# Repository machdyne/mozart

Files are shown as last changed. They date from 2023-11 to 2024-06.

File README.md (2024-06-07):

# Mozart Motherboard

Mozart is a motherboard that when paired with a [Sechzig](https://github.com/machdyne/sechzig) compute module can function as a computer.

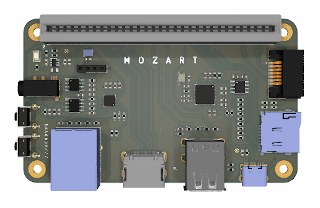
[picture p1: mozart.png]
Mozart Motherboard


This repo contains schematics, PCB layouts, pinouts and documentation.

Find more information on the [Mozart product page](https://machdyne.com/product/mozart-motherboard/).

## Using Mozart

Mozart requires a Sechzig module to power on. **When inserting a Sechzig module, make sure that pin 2 on Mozart and pin 2 on the module are both on the same side.**

## Firmware

Mozart has a JTAG and USB CDC interface that are both accessible on the USB-C port. These interfaces are provided by a [fork of pico-dirtyJtag](https://github.com/machdyne/mozart/tree/main/firmware). You can update the RP2040 firmware by holding down the BOOT button and then applying power.

To build the firmware from source:

```
$ cd firmware/pico-dirtyJtag
$ mkdir build
# if your Mozart has Zetta flash:
$ cmake ..
# or if your Mozart has Adesto flash:
$ cmake .. -DPICO_DEFAULT_BOOT_STAGE2_FILE=/your-pico-sdk-directory/pico-sdk/src/rp2_common/boot_stage2/boot2_generic_03h.S
# then
$ make
```

## Programming

Program the configuration SRAM of a Sechzig module:

```
sudo openFPGALoader -c dirtyJtag image.bit
```

Program the configuration flash on a Sechzig ML module:

```
sudo openFPGALoader -f -c dirtyJtag image.bit
```

Program the configuration flash on a Sechzig MX1 module:

```
sudo openFPGALoader -c dirtyJtag -f image.bit --fpga-part xc7a35tftg256
```

## Linux

See the [Kakao Linux](https://github.com/machdyne/kakao) repo for the latest instructions.

## Pinouts

### LVDS Port

Mozart has an experimental SATA-style LVDS port. SATA is not supported.

| Pin | Signal |
| --- | --- |
| 1 | GND |
| 2 | DS2\_P |
| 3 | DS2\_N |
| 4 | GND |
| 5 | DS1\_P |
| 6 | DS1\_N |
| 7 | GND |

### Audio Jack

Mozart has line-level audio output via a 3.5mm jack.

| Pin | Signal |
| --- | --- |
| S | GND |
| R2 | NC |
| R1 | AUDIO\_R |
| T | AUDIO\_L |

### Audio Amp Port

Mozart has a socket for an optional audio amplifier, so that speakers
can be connected to the DAC output.

| Pin | Signal |
| --- | --- |
| 1 | 5V0 |
| 2 | AUDIO\_L |
| 3 | AUDIO\_R |
| 4 | GND |

### DDMI Port

See the [DDMI repo](https://github.com/machdyne/ddmi) for details.

## Funding

This project was partially funded through the NGI0 Entrust Fund, a fund established by NLnet with financial support from the European Commission's Next Generation Internet programme.

## License

This project is released under the [CERN-OHL-P](LICENSE.txt) license.

Note: You can use these designs for commercial purposes but we ask that instead of producing exact clones, that you either replace our trademarks and logos with your own or add your own next to ours.

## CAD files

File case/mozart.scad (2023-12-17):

/*
 * Mozart Case
 * Copyright (c) 2023 Lone Dynamics Corporation. All rights reserved.
 *
 * required hardware:
 *  - 2 x M3 x 12mm bolts
 *  - 2 x M3 x 25mm countersunk bolts
 *  - 4 x M3 nuts
 * 
 */

$fn = 100;

board_width = 60;
board_thickness = 1.404;
board_length = 100;
board_height = 1.6;
board_spacing = 2;

wall = 1.5;

//translate([1,2,-1.6]) ld9_board();

translate([0,0,0])
	ld9_case_top();

translate([0,0,-6.5])
	ld9_case_bottom();

module ld9_board() {
	
	difference() {
		union() {
			color([0,0.5,0])
				roundedcube(board_width,board_length,board_thickness, 5);
			color([0.2,0.2,0.2])
				translate([0.75,8,0]) cube([9.2, 82.7, 55]);
				//translate([0.25,8,0]) cube([9.2, 82.7, 15]);
			color([0.2,0.2,0.2])
				translate([35.725-(7.5/2),-5,0])
					cube([7.5,10,7.5]);

		}
		translate([5, 5, -1]) cylinder(d=3.2, h=100);
		translate([5, 95, -1]) cylinder(d=3.2, h=100);
		translate([55, 5, -1]) cylinder(d=3.2, h=100);
		translate([55, 95, -1]) cylinder(d=3.2, h=100);
	}	
		
}

module ld9_case_top() {

		translate([0,25,19])
				rotate([90,0,270])
					translate([-45,-11,5])
						linear_extrude(1)
							text("M O Z A R T", size=4, halign="center",
								font="Liberation Sans:style=Bold");


		// addl supports
		translate([35.725-(7.5/2)-2.25,2,0]) cube([3.25,2.5,20]);
		translate([46.4-(7.5/2)-2.25,2,0]) cube([3.25,2.5,20]);
		translate([41.5-(7.5/2)-6.75,101,0]) cube([4,1.5,20]);

		translate([58,30.25,0]) cube([4,8,20]);
		translate([58,53.75,0]) cube([4,6.25,20]);
		translate([58,75,0]) cube([4,6.25,20]);

		translate([-3,37,0]) cube([3,30,20]);
		translate([-3,2,0]) cube([3,25,20]);
		translate([-3,77,0]) cube([3,25,20]);

				
		translate([1,2,0]) {
			difference() {
				union() {
					translate([52,0,0]) cube([9,9,20]);
					translate([51.2,91.2,0]) cube([9,9,20]);
				}		
				// bolt holes
				translate([55,5,0]) cylinder(d=3.2, h=50);
				translate([55,95,0]) cylinder(d=3.2, h=50);
				translate([55,5,18.5]) cylinder(d=6, h=2);
				translate([55,95,18.5]) cylinder(d=6, h=2);

			}
			difference() {
				translate([2.5,4,2.75]) cube([15,8,5.5], center=true);
				translate([5,5,0]) cylinder(d=3.2, h=50);
			}
			difference() {
				translate([2.5,96,2.75]) cube([15,8,5.5], center=true);
				translate([5,95,0]) cylinder(d=3.2, h=50);
			}

		}
	
		difference () {
			
			// body			
			union() {
				translate([-5,0,0]) roundedcube(68,104,20,5);
			}
			
			translate([1,2,-0.1]) {
				
				translate([-4,0,0]) roundedcube(board_width+4,board_length,20-2,5);
				
				// sechzig module
				
				translate([-1,(board_length/2)-(95.5/2),0])
					cube([13.5,95.5,50]);
				
				translate([-2.25,board_length/2+20,0])
					cube([2.5,10,50], center=true);
				
				translate([-2.25,board_length/2-20,0])
					cube([2.5,10,50], center=true);
			
				// ethernet
				translate([55,20-(16.5/2),0])
					cube([10,16.5,15]);

				// hdmi
				translate([55,44-(15.5/2),0])
					cube([10,15.5,7]);
			
				// usb host
				translate([55,65.5-(15/2),0])
					cube([10,15,16.25]);

				// usb-c
				translate([55,84-(9.5/2),0])
					cube([10,9.5,3.25]);

				// activity LED
				translate([13.5,-5,3])
					cube([1.5,10,1.5]);

				// audio jack
				translate([25.5-(6.5/2),-5,0])
					cube([6.5,10,6]);

				// reset button
				translate([35.725-(7.5/2),-5,0])
					cube([7.5,10,7.5]);

				// boot button
				translate([46.4-(7.5/2),-5,0])
					cube([7.5,10,7.5]);

				// sd card
				translate([41.5-(15/2),95,0])
					cube([15,10,3]);

				// expansion
				translate([21-(18/2),95,0])
					cube([18,10,6]);

				// bolt holes
				translate([55,5,0]) cylinder(d=3.2, h=50);
				translate([55,95,0]) cylinder(d=3.2, h=50);

				translate([55,5,18.5]) cylinder(d=6, h=3);
				translate([55,95,18.5]) cylinder(d=6, h=3);
				
				translate([0,25,19])
					rotate([0,0,90])
						translate([45,-45,0.5])
							linear_extrude(1)
								text("M O Z A R T", size=4, halign="center",
									font="Liberation Sans:style=Bold");
		
		
			}

		}
	
				
		
}

module ld9_case_bottom() {

		difference () {
			
			union() {
				translate([-5,0,0]) roundedcube(68,104,6.5,5);
//				translate([-9,104/2-25/2,0]) cube([4,25,15]);
//				translate([-5,104/2-25/2,0]) cylinder(d=8, h=5);
//				translate([-5,104/2+25/2,0]) cylinder(d=8, h=5);
			}
			
//			translate([-10,104/2-10.5/2,5]) cube([20,10.5,7]);
			
			translate([1,2,0]) {				
				
				translate([8.5,-0.1,2]) roundedcube(board_width-8.5-9,board_length+0.2,5,5);
				translate([-4,9,2]) roundedcube(board_width+4,board_length-18,5,5);
			
				translate([-0.125,-0.125,6.5-1.6]) roundedcube(board_width+0.25,board_length+0.25,10, 5);
				
				// bolt holes
				translate([5,5,0]) cylinder(d=3.2, h=50);
				translate([5,95,0]) cylinder(d=3.2, h=50);
				translate([55,5,0]) cylinder(d=3.2, h=50);
				translate([55,95,0]) cylinder(d=3.2, h=50);

				// nut holes
				translate([5,5,-1.75]) cylinder(d=7, h=4.5, $fn=6);
				translate([5,95,-1.75]) cylinder(d=7, h=4.5, $fn=6);
				translate([55,5,-1.75]) cylinder(d=7, h=4.5, $fn=6);
				translate([55,95,-1.75]) cylinder(d=7, h=4.5, $fn=6);


			}

		}
		
}

// https://gist.github.com/tinkerology/ae257c5340a33ee2f149ff3ae97d9826
module roundedcube(xx, yy, height, radius)
{
    translate([0,0,height/2])
    hull()
    {
        translate([radius,radius,0])
        cylinder(height,radius,radius,true);

        translate([xx-radius,radius,0])
        cylinder(height,radius,radius,true);

        translate([xx-radius,yy-radius,0])
        cylinder(height,radius,radius,true);

        translate([radius,yy-radius,0])
        cylinder(height,radius,radius,true);
    }
}

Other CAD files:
case/mozart_box.scad

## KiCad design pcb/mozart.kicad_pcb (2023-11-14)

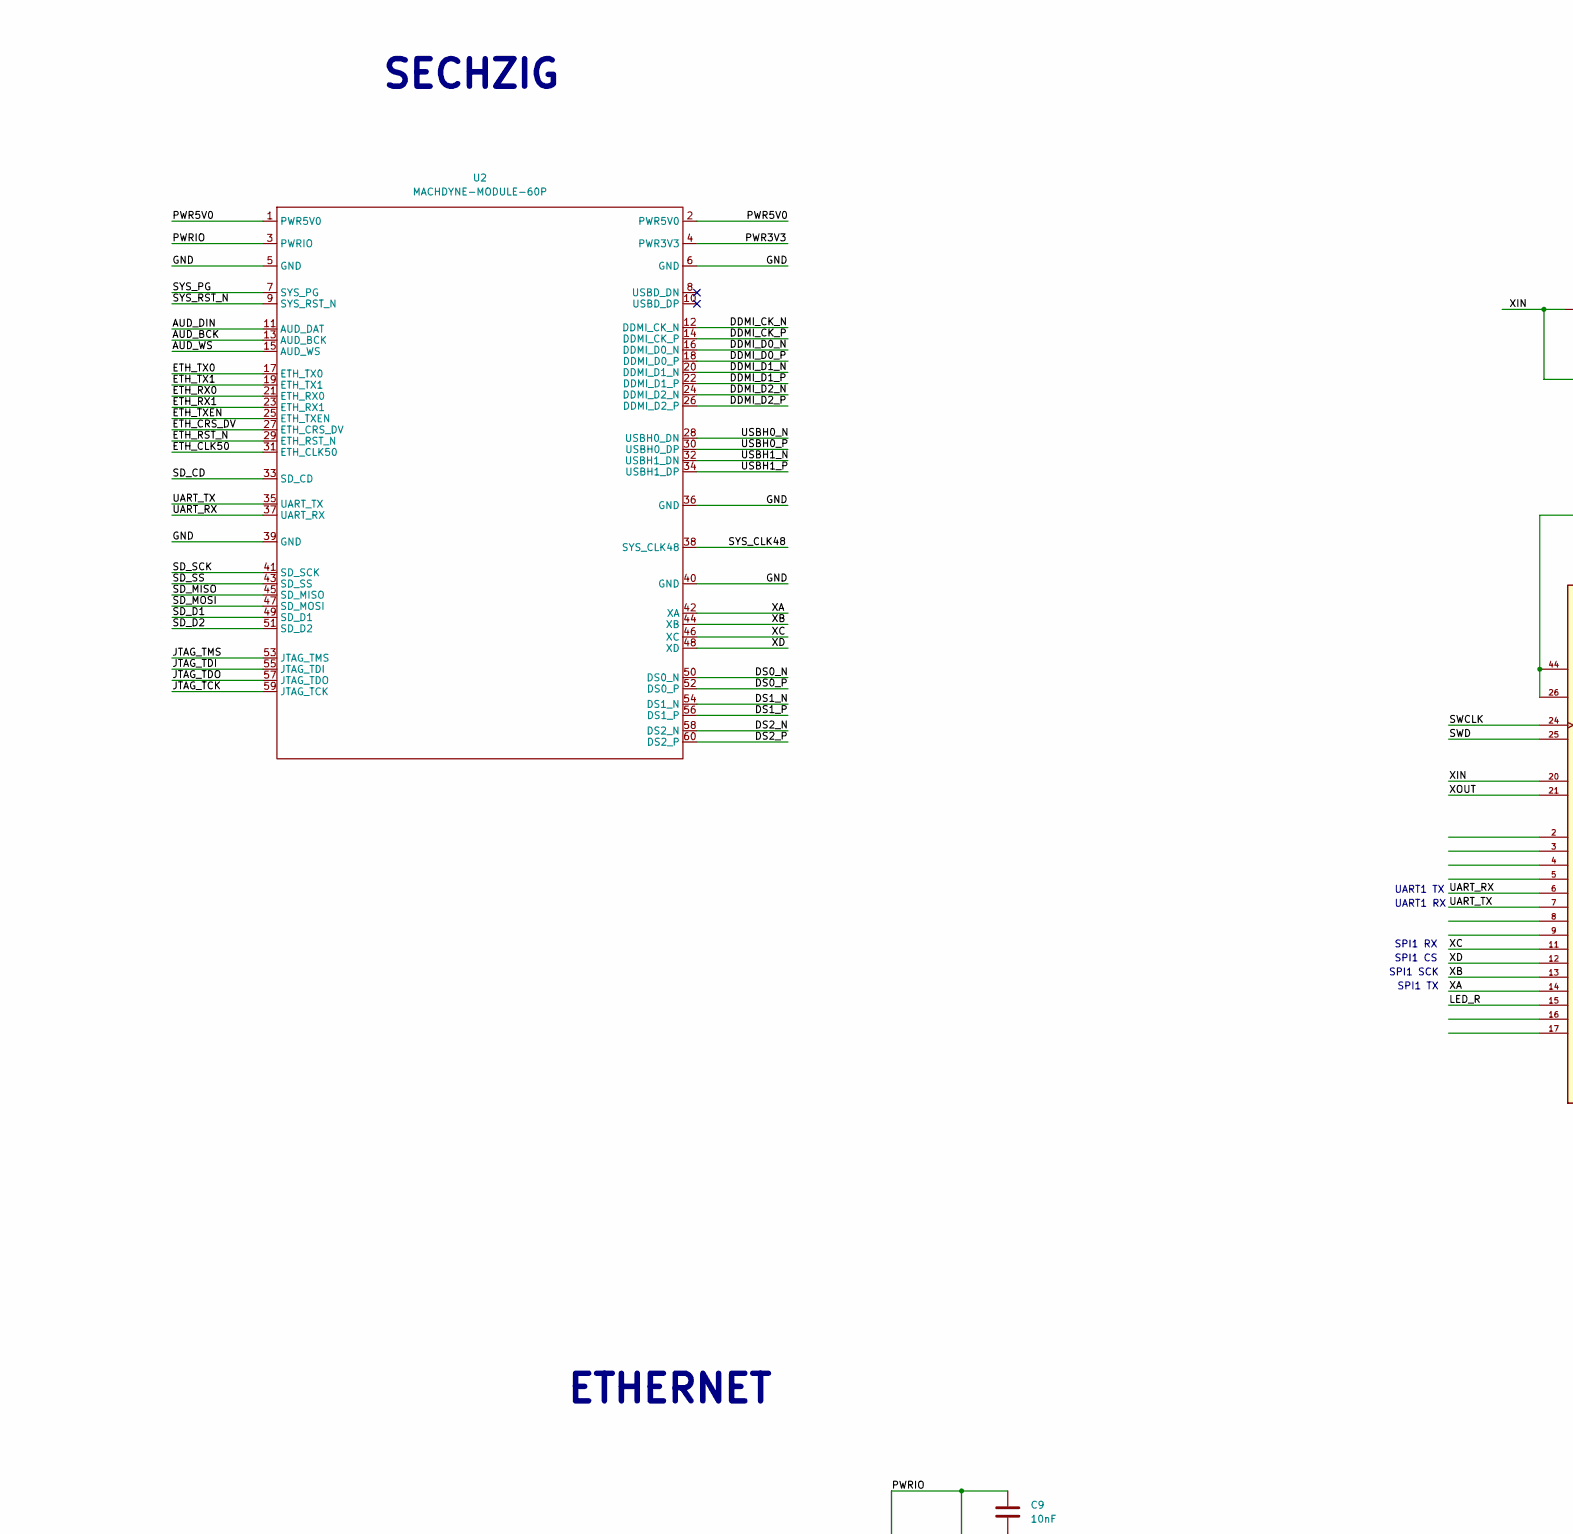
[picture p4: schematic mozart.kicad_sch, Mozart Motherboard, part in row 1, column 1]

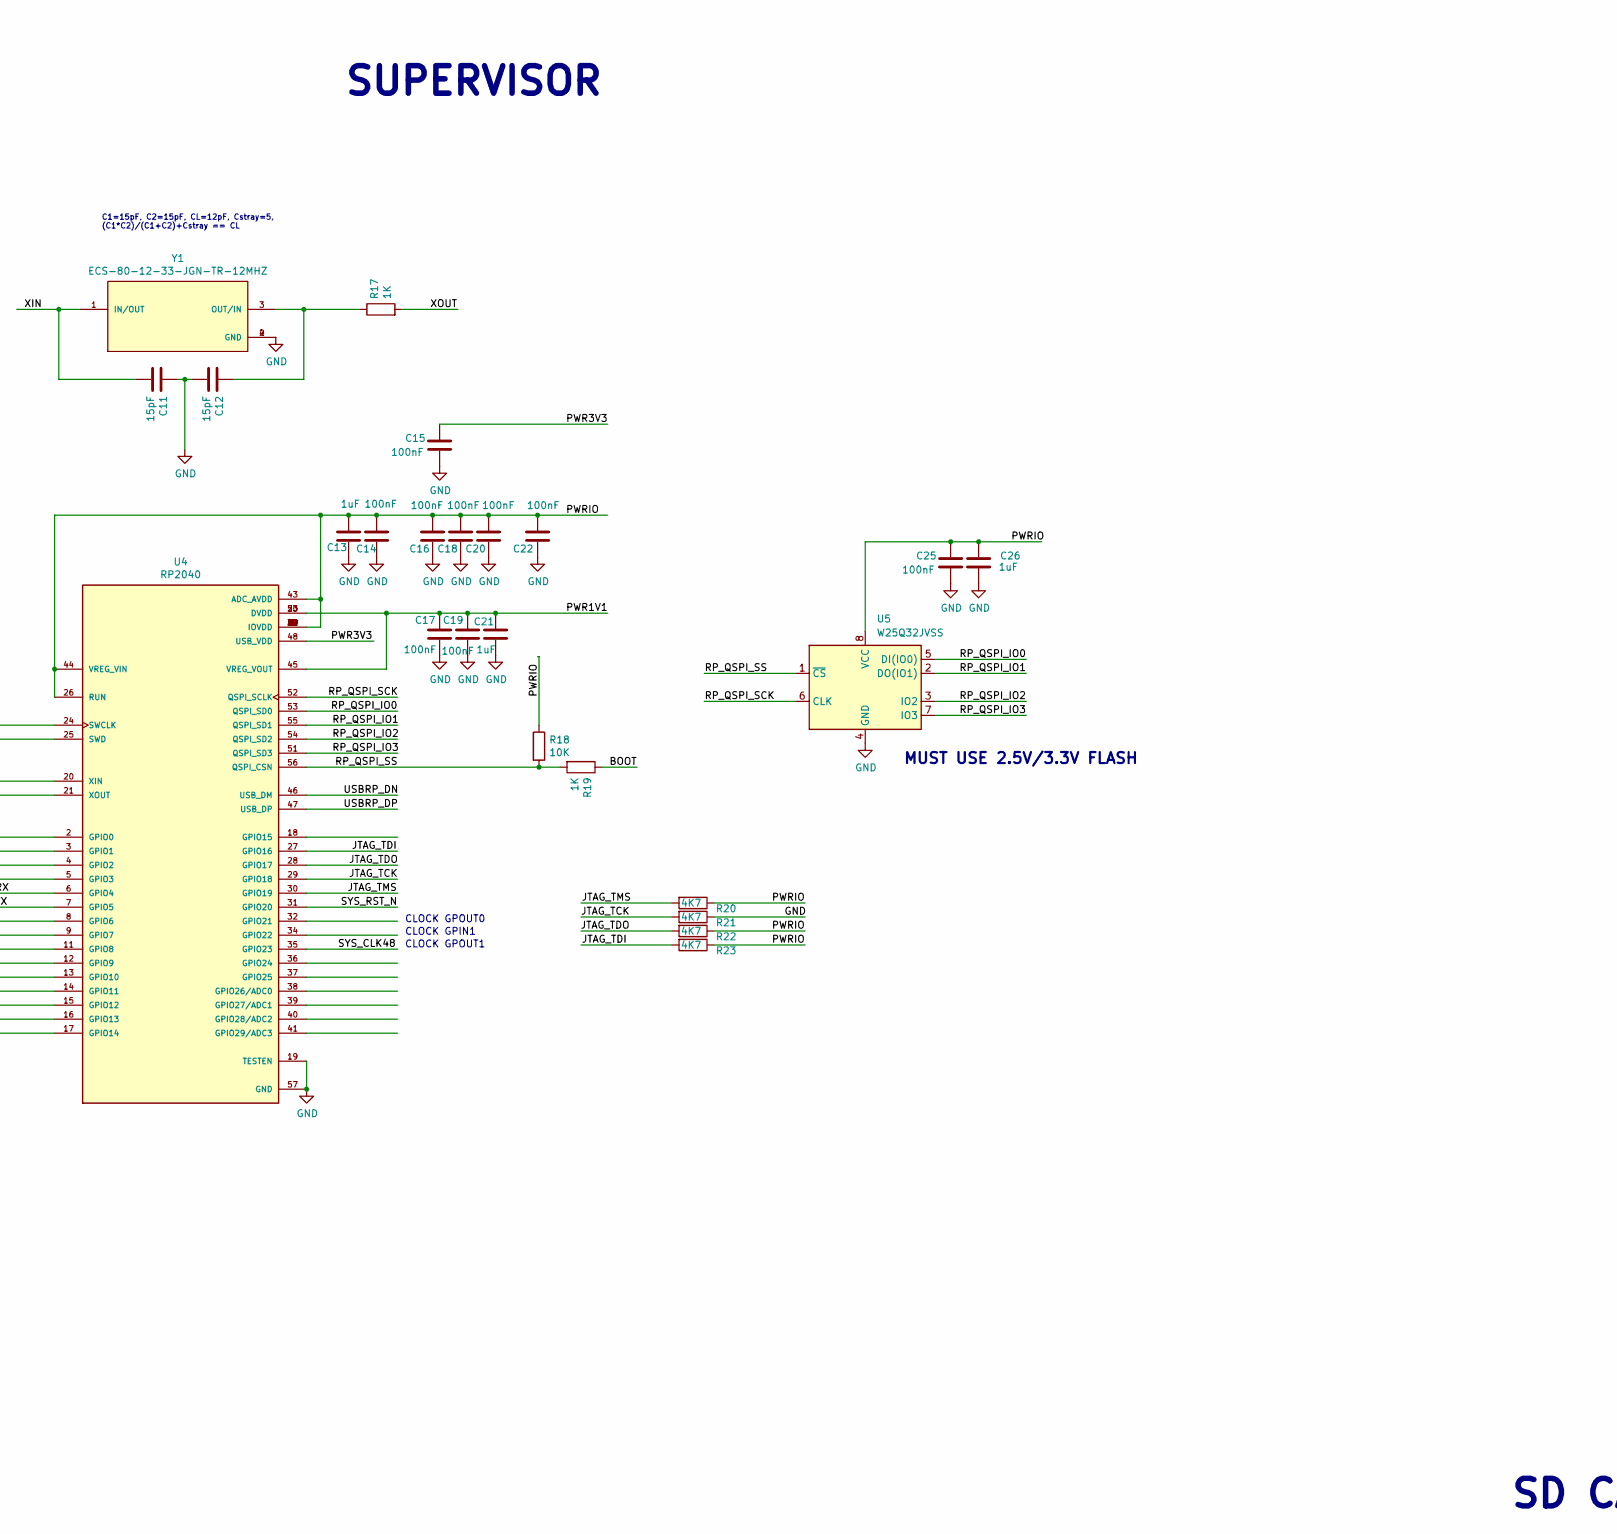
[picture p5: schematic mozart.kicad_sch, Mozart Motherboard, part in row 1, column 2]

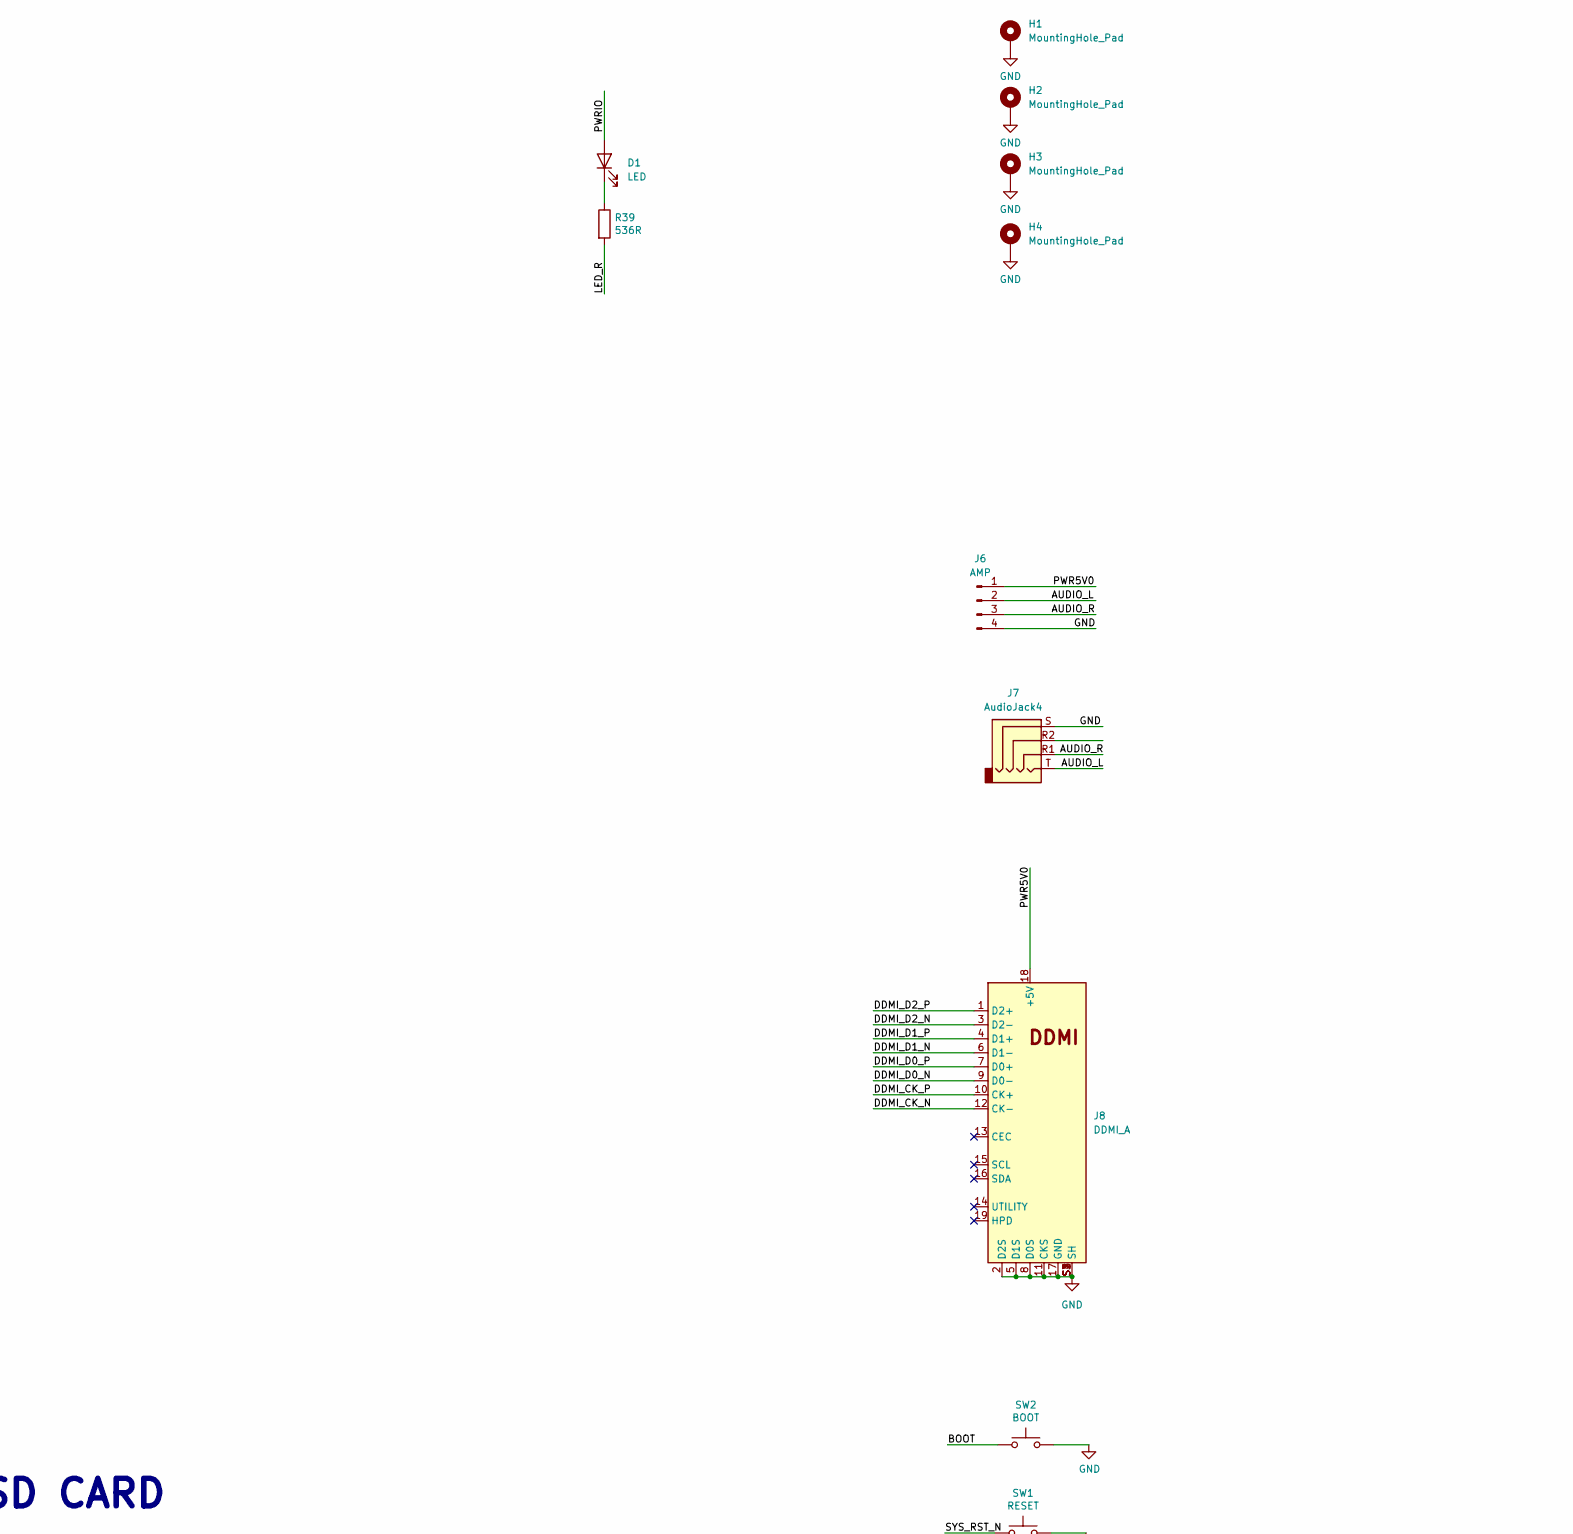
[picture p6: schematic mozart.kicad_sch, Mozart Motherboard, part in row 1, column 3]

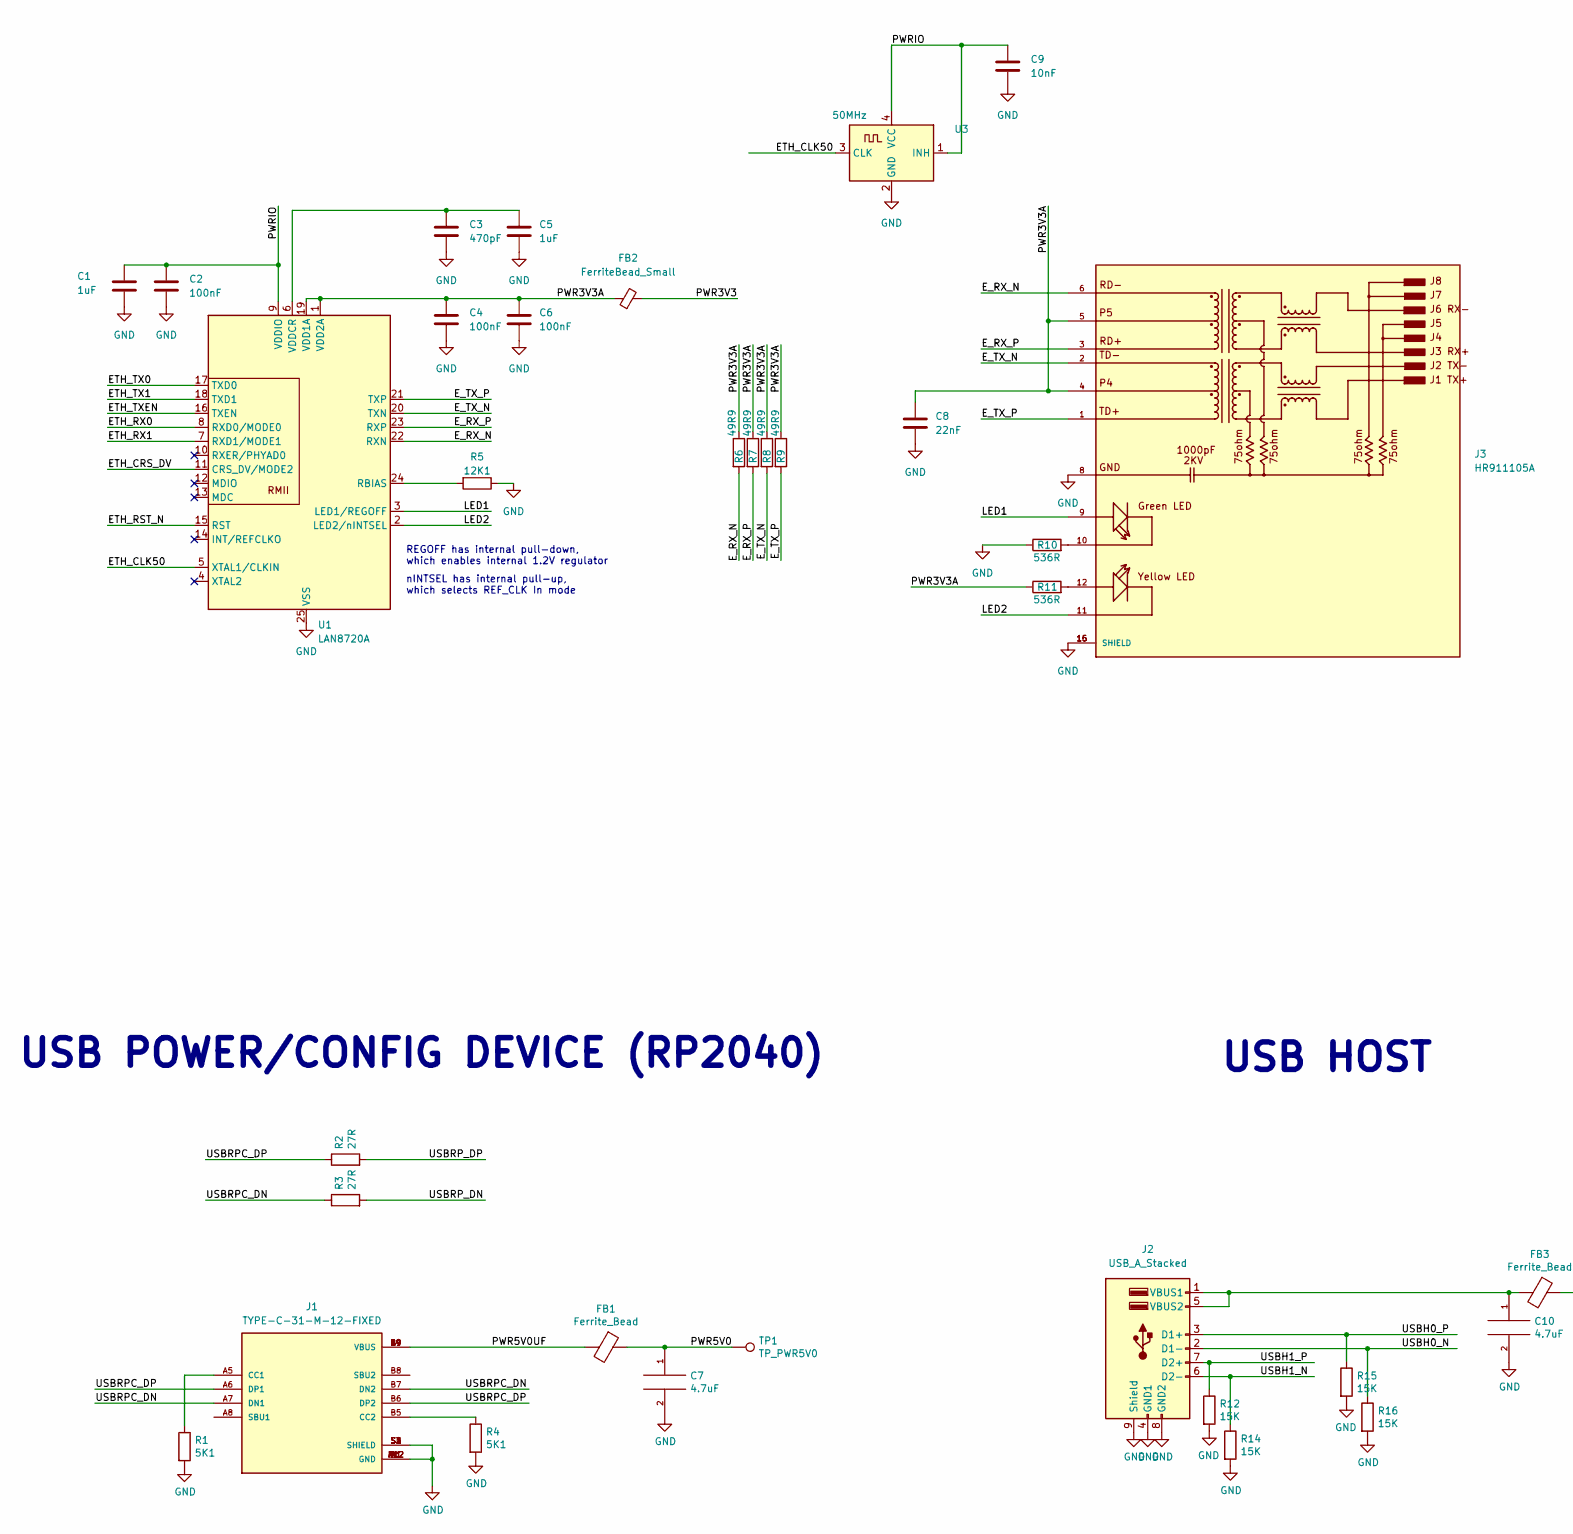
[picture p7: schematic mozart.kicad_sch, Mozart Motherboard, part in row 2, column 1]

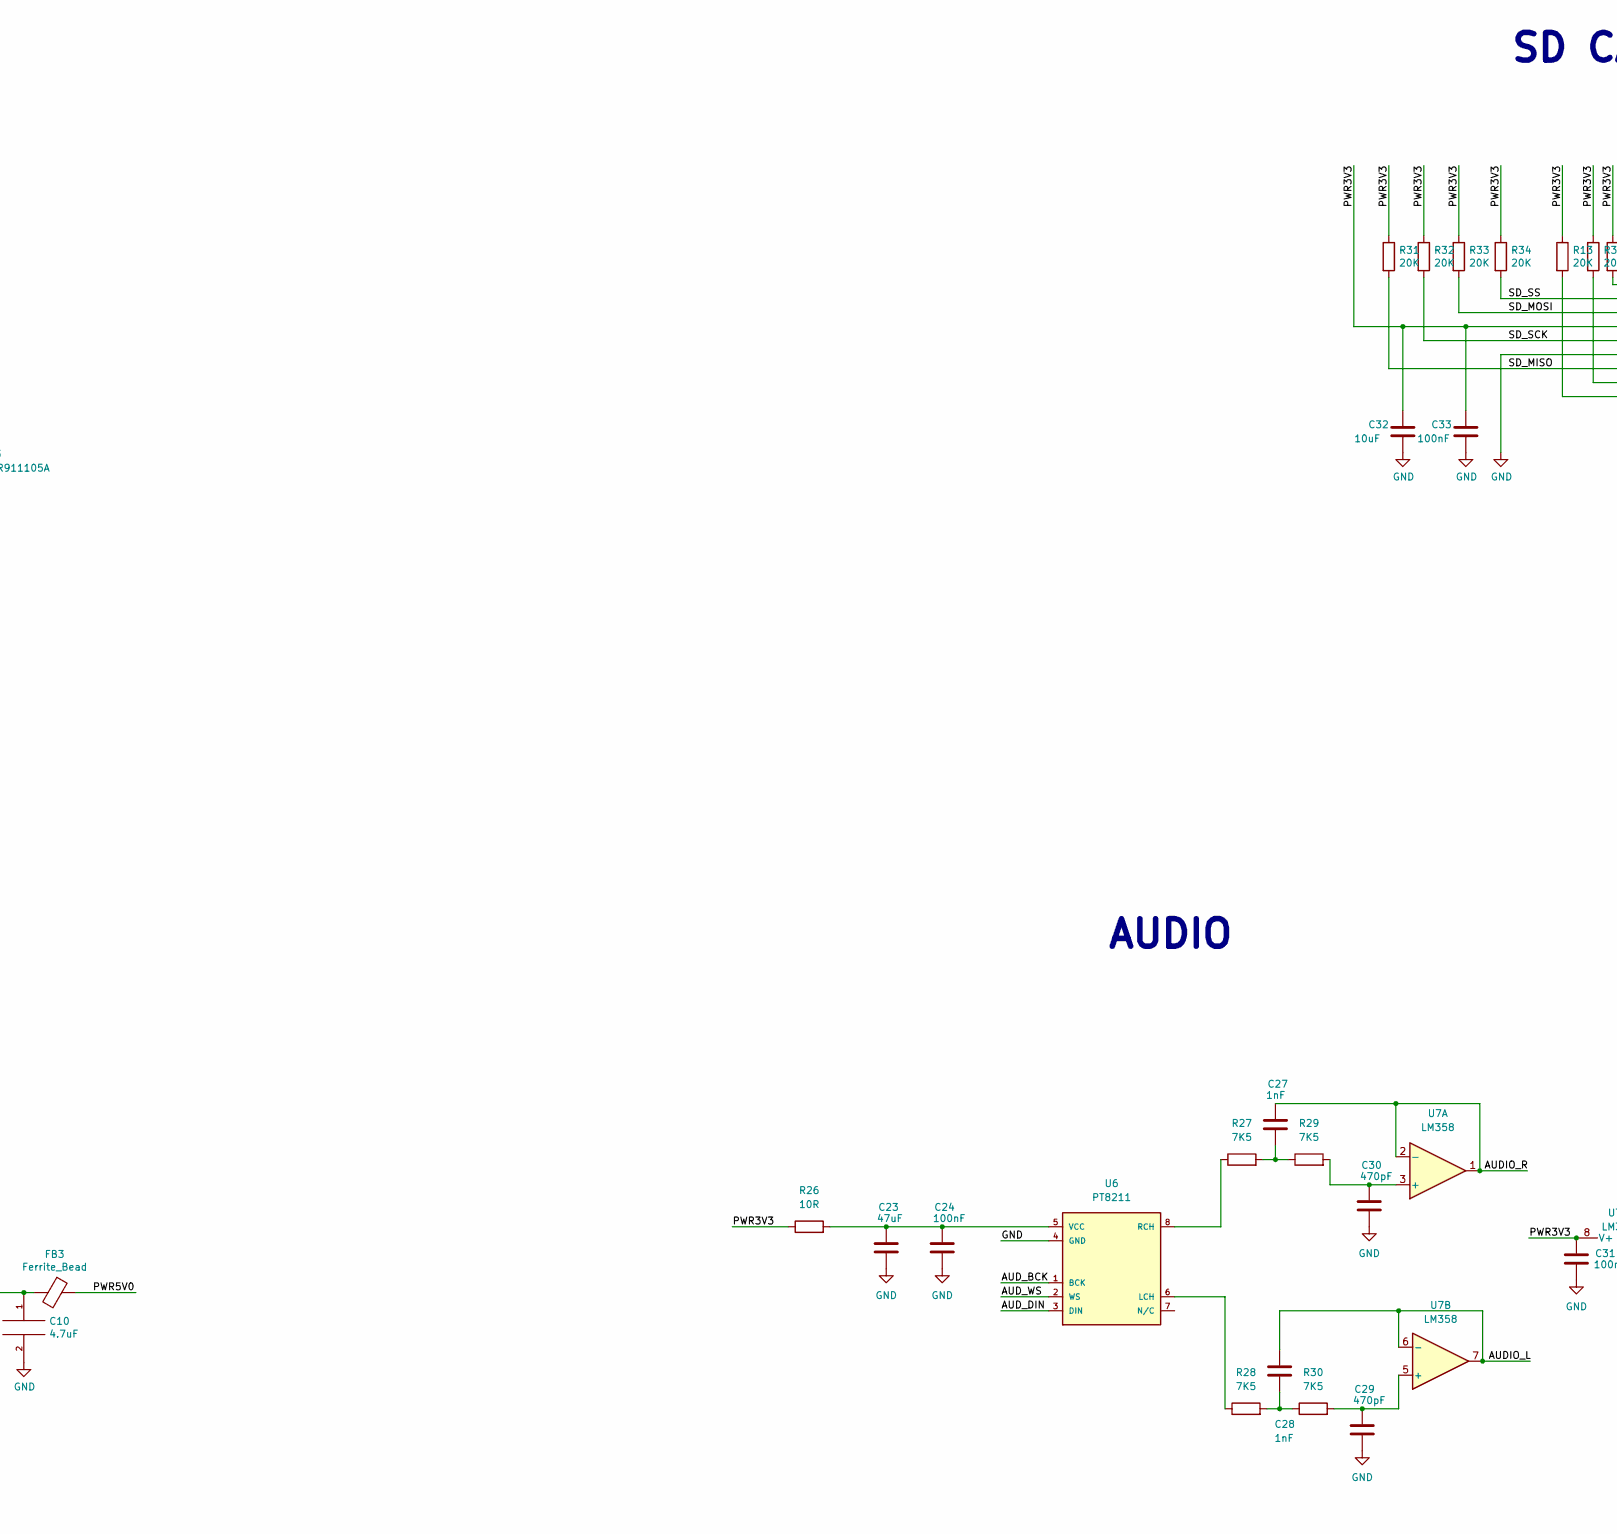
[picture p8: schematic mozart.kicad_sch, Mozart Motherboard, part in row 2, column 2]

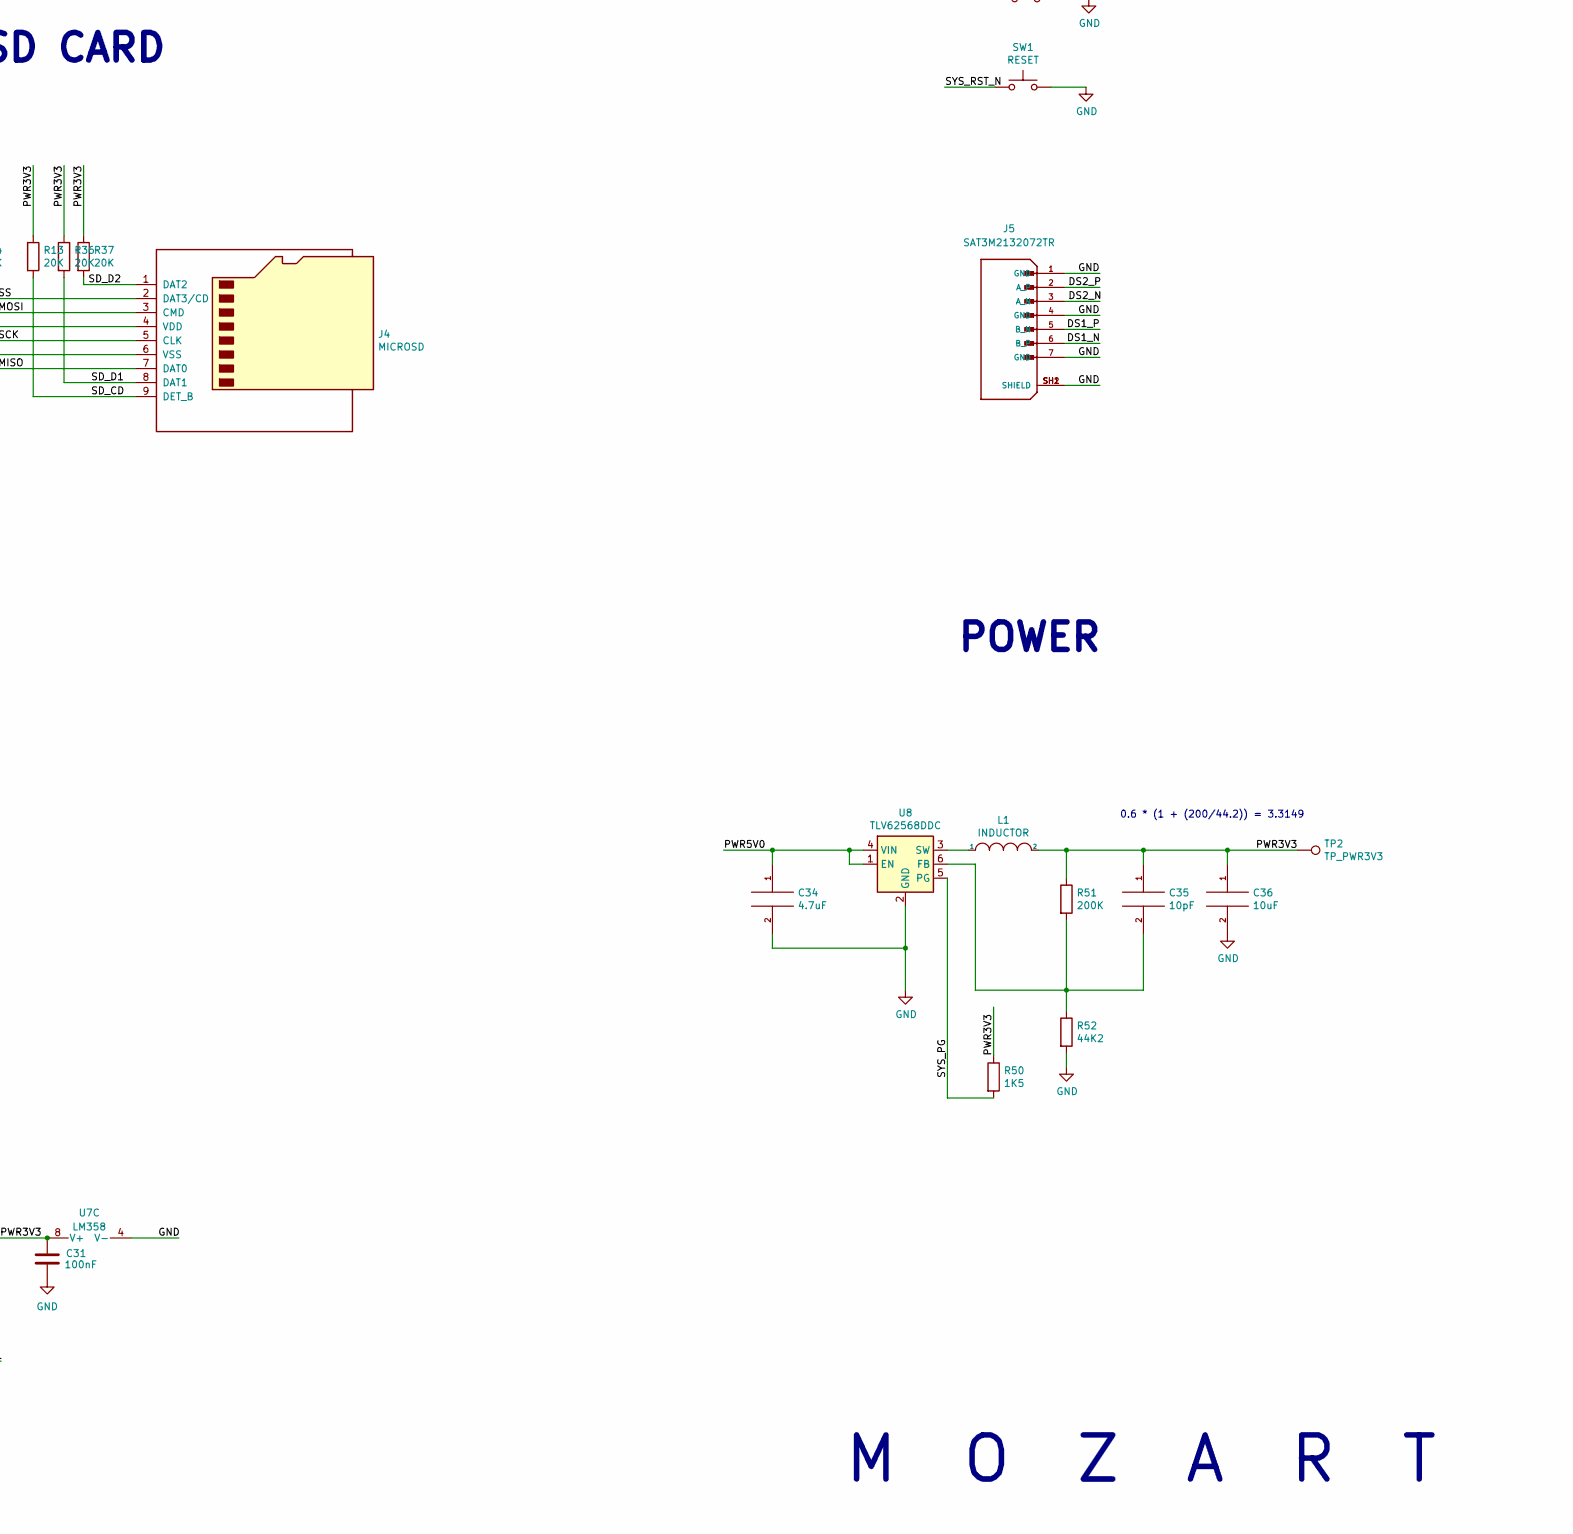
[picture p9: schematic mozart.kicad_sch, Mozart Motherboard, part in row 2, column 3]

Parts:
C1, C5, C13, C21, C26: 1uF; C_0603_1608Metric
C2, C4, C6, C14, C15, C16, C17, C18, C19, C20, C22, C24, C25, C31: 100nF; C_0603_1608Metric
C3, C29, C30: 470pF; C_0603_1608Metric
C7, C10, C34: 4.7uF; C_0603_1608Metric
C8: 22nF; C_0603_1608Metric
C9: 10nF; C_0603_1608Metric
C11, C12: 15pF; C_0603_1608Metric
C23: 47uF; C_0603_1608Metric
C27, C28: 1nF; C_0603_1608Metric
C32: 10uF; R_0603_1608Metric
C33: 100nF; R_0603_1608Metric
C35: 10pF; C_0603_1608Metric
C36: 10uF; C_0603_1608Metric
D1: LED; LED_1206_3216Metric
FB1, FB3: Ferrite_Bead; R_0603_1608Metric
FB2: FerriteBead_Small; R_0603_1608Metric
H1, H2, H3, H4: MountingHole_Pad; MountingHole_3.2mm_M3_Pad
J1: TYPE-C-31-M-12-FIXED; USB_C_Receptacle_HRO_TYPE-C-31-M-12-BIG-PADS; PARTREV A
J2: USB_A_Stacked; USB_A_Wuerth_61400826021_Horizontal_Stacked
J3: HR911105A; HANRUN_HR911105A; PARTREV A
J4: MICROSD; SDCARD
J5: SAT3M2132072TR; AMPHENOL_SAT3M2132072TR; PARTREV 1
J6: AMP; PinSocket_1x04_P2.54mm_Vertical
J7: AudioJack4; Jack_3.5mm_PJ320D_Horizontal
J8: DDMI_A; HDMI_TE_1827059-3-FIXED
L1: INDUCTOR; L_0805_2012Metric
R1, R4: 5K1; R_0603_1608Metric
R2, R3: 27R; R_0603_1608Metric
R5: 12K1; R_0603_1608Metric
R6, R7, R8, R9: 49R9; R_0603_1608Metric
R10, R11, R39: 536R; R_0603_1608Metric
R12, R14, R15, R16: 15K; R_0603_1608Metric
R13, R31, R32, R33, R34, R36, R37: 20K; R_0603_1608Metric
R17, R19: 1K; R_0603_1608Metric
R18: 10K; R_0603_1608Metric
R20, R21, R22, R23: 4K7; R_0603_1608Metric
R26: 10R; R_0603_1608Metric
R27, R28, R29, R30: 7K5; R_0603_1608Metric
R50: 1K5; R_0603_1608Metric
R51: 200K; R_0603_1608Metric
R52: 44K2; R_0603_1608Metric
SW1: RESET; SW_Tactile_SPST_Angled_PTS645Vx39-2LFS
SW2: BOOT; SW_Tactile_SPST_Angled_PTS645Vx39-2LFS
TP1: TP_PWR5V0; TestPoint_THTPad_D1.0mm_Drill0.5mm
TP2: TP_PWR3V3; TestPoint_THTPad_D1.0mm_Drill0.5mm
U1: LAN8720A; QFN-24-1EP_4x4mm_P0.5mm_EP2.6x2.6mm
U2: MACHDYNE-MODULE-60P; MACHDYNE_EDGE_SOCKET_60P
U3: 50MHz; Oscillator_SMD_Kyocera_KC2520Z-4Pin_2.5x2.0mm
U4: RP2040; RP2040-QFN-56-OFFICIAL; PARTREV 1.6.1
U5: W25Q32JVSS; SOIC-8_3.9x4.9mm_P1.27mm
U6: PT8211; SOP-8_3.9x4.9mm_P1.27mm
U7: LM358
U8: TLV62568DDC; SOT-23-6
Y1: ECS-80-12-33-JGN-TR-12MHZ; XTAL_ECS-240-8-33-AGN-TR

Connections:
/AUDIO_L: C28.1, J6.2, J7.T, U7.6 (-), U7.7
/AUDIO_R: C27.1, J6.3, J7.R1, U7.1, U7.2 (-)
/AUD_BCK: U2.13 (AUD_BCK), U6.1 (BCK)
/AUD_DIN: U2.11 (AUD_DAT), U6.3 (DIN)
/AUD_WS: U2.15 (AUD_WS), U6.2 (WS)
/BOOT: R19.1, SW2.1
/DDMI_CK_N: J8.12 (CK-), U2.12 (DDMI_CK_N)
/DDMI_CK_P: J8.10 (CK+), U2.14 (DDMI_CK_P)
/DDMI_D0_N: J8.9 (D0-), U2.16 (DDMI_D0_N)
/DDMI_D0_P: J8.7 (D0+), U2.18 (DDMI_D0_P)
/DDMI_D1_N: J8.6 (D1-), U2.20 (DDMI_D1_N)
/DDMI_D1_P: J8.4 (D1+), U2.22 (DDMI_D1_P)
/DDMI_D2_N: J8.3 (D2-), U2.24 (DDMI_D2_N)
/DDMI_D2_P: J8.1 (D2+), U2.26 (DDMI_D2_P)
/DS0_N: U2.50 (DS0_N)
/DS0_P: U2.52 (DS0_P)
/DS1_N: J5.6 (B_P), U2.54 (DS1_N)
/DS1_P: J5.5 (B_N), U2.56 (DS1_P)
/DS2_N: J5.3 (A_N), U2.58 (DS2_N)
/DS2_P: J5.2 (A_P), U2.60 (DS2_P)
/ETH_CLK50: U1.5 (XTAL1/CLKIN), U2.31 (ETH_CLK50), U3.3 (CLK)
/ETH_CRS_DV: U1.11 (CRS_DV/MODE2), U2.27 (ETH_CRS_DV)
/ETH_RST_N: U1.15 (RST), U2.29 (ETH_RST_N)
/ETH_RX0: U1.8 (RXD0/MODE0), U2.21 (ETH_RX0)
/ETH_RX1: U1.7 (RXD1/MODE1), U2.23 (ETH_RX1)
/ETH_TX0: U1.17 (TXD0), U2.17 (ETH_TX0)
/ETH_TX1: U1.18 (TXD1), U2.19 (ETH_TX1)
/ETH_TXEN: U1.16 (TXEN), U2.25 (ETH_TXEN)
/E_RX_N: J3.6, R6.2, U1.22 (RXN)
/E_RX_P: J3.3, R7.2, U1.23 (RXP)
/E_TX_N: J3.2, R8.2, U1.20 (TXN)
/E_TX_P: J3.1, R9.2, U1.21 (TXP)
/JTAG_TCK: R21.2, U2.59 (JTAG_TCK), U4.29 (GPIO18)
/JTAG_TDI: R23.2, U2.55 (JTAG_TDI), U4.27 (GPIO16)
/JTAG_TDO: R22.2, U2.57 (JTAG_TDO), U4.28 (GPIO17)
/JTAG_TMS: R20.2, U2.53 (JTAG_TMS), U4.30 (GPIO19)
/LED1: J3.9, U1.3 (LED1/REGOFF)
/LED2: J3.11, U1.2 (LED2/nINTSEL)
/LED_R: R39.2, U4.15 (GPIO12)
/PWR1V1: C17.1, C19.1, C21.1, U4.23 (DVDD), U4.45 (VREG_VOUT), U4.50 (DVDD)
/PWR3V3: C15.1, C31.1, C32.1, C33.1, C35.1, C36.1, FB2.2, J4.4 (VDD), L1.2, R13.1, R26.1, R31.1, R32.1, R33.1, R34.1, R36.1, R37.1, R50.1, R51.1, TP2.1, U2.4 (PWR3V3), U4.48 (USB_VDD), U7.8 (V+)
/PWR3V3A: C4.1, C6.1, C8.1, FB2.1, J3.4, J3.5, R6.1, R7.1, R8.1, R9.1, R11.1, U1.1 (VDD2A), U1.19 (VDD1A)
/PWR5V0: C7.1, C34.1, FB1.1, FB3.1, J6.1, J8.18 (+5V), TP1.1, U2.1 (PWR5V0), U2.2 (PWR5V0), U8.1 (EN), U8.4 (VIN)
/PWR5V0UF: FB1.2, J1.A4 (VBUS), J1.A9 (VBUS), J1.B4 (VBUS), J1.B9 (VBUS)
/PWRIO: C1.1, C2.1, C9.1, C13.1, C14.1, C16.1, C18.1, C20.1, C22.1, C25.1, C26.1, D1.2 (A), R18.1, R20.1, R22.1, R23.1, U1.9 (VDDIO), U2.3 (PWRIO), U3.1 (INH), U3.4 (VCC), U4.1 (IOVDD), U4.10 (IOVDD), U4.22 (IOVDD), U4.26 (RUN), U4.33 (IOVDD), U4.42 (IOVDD), U4.43 (ADC_AVDD), U4.44 (VREG_VIN), U4.49 (IOVDD), U5.8 (VCC)
/RP_QSPI_IO0: U4.53 (QSPI_SD0), U5.5 (DI(IO0))
/RP_QSPI_IO1: U4.55 (QSPI_SD1), U5.2 (DO(IO1))
/RP_QSPI_IO2: U4.54 (QSPI_SD2), U5.3 (IO2)
/RP_QSPI_IO3: U4.51 (QSPI_SD3), U5.7 (IO3)
/RP_QSPI_SCK: U4.52 (QSPI_SCLK), U5.6 (CLK)
/RP_QSPI_SS: R18.2, R19.2, U4.56 (QSPI_CSN), U5.1 (~CS)
/SD_CD: J4.9 (DET_B), R13.2, U2.33 (SD_CD)
/SD_D1: J4.8 (DAT1), R36.2, U2.49 (SD_D1)
/SD_D2: J4.1 (DAT2), R37.2, U2.51 (SD_D2)
/SD_MISO: J4.7 (DAT0), R31.2, U2.45 (SD_MISO)
/SD_MOSI: J4.3 (CMD), R33.2, U2.47 (SD_MOSI)
/SD_SCK: J4.5 (CLK), R32.2, U2.41 (SD_SCK)
/SD_SS: J4.2 (DAT3/CD), R34.2, U2.43 (SD_SS)
/SWCLK: U4.24 (SWCLK)
/SWD: U4.25 (SWD)
/SYS_CLK48: U2.38 (SYS_CLK48), U4.35 (GPIO23)
/SYS_PG: R50.2, U2.7 (SYS_PG), U8.5 (PG)
/SYS_RST_N: SW1.1, U2.9 (SYS_RST_N), U4.31 (GPIO20)
/UART_RX: U2.37 (UART_RX), U4.6 (GPIO4)
/UART_TX: U2.35 (UART_TX), U4.7 (GPIO5)
/USBH0_N: J2.2 (D1-), R16.1, U2.28 (USBH0_DN)
/USBH0_P: J2.3 (D1+), R15.1, U2.30 (USBH0_DP)
/USBH1_N: J2.6 (D2-), R14.1, U2.32 (USBH1_DN)
/USBH1_P: J2.7 (D2+), R12.1, U2.34 (USBH1_DP)
/USBRPC_DN: J1.A7 (DN1), J1.B7 (DN2), R3.1
/USBRPC_DP: J1.A6 (DP1), J1.B6 (DP2), R2.1
/USBRP_DN: R3.2, U4.46 (USB_DM)
/USBRP_DP: R2.2, U4.47 (USB_DP)
/XA: U2.42 (XA), U4.14 (GPIO11)
/XB: U2.44 (XB), U4.13 (GPIO10)
/XC: U2.46 (XC), U4.11 (GPIO8)
/XD: U2.48 (XD), U4.12 (GPIO9)
/XIN: C11.2, U4.20 (XIN), Y1.1 (IN/OUT)
/XOUT: R17.2, U4.21 (XOUT)
GND: C1.2, C2.2, C3.2, C4.2, C5.2, C6.2, C7.2, C8.2, C9.2, C10.2, C11.1, C12.2, C13.2, C14.2, C15.2, C16.2, C17.2, C18.2, C19.2, C20.2, C21.2, C22.2, C23.2, C24.2, C25.2, C26.2, C29.2, C30.2, C31.2, C32.2, C33.2, C34.2, C36.2, H1.1, H2.1, H3.1, H4.1, J1.A1 (GND), J1.A12 (GND), J1.B1 (GND), J1.B12 (GND), J1.S1 (SHIELD), J1.S2 (SHIELD), J1.S3 (SHIELD), J1.S4 (SHIELD), J2.4 (GND1), J2.8 (GND2), J2.9 (Shield), J3.8, J3.15 (SHIELD), J3.16 (SHIELD), J4.6 (VSS), J5.1 (GND), J5.4 (GND), J5.7 (GND), J5.SH1 (SHIELD), J5.SH2 (SHIELD), J6.4, J7.S, J8.2 (D2S), J8.5 (D1S), J8.8 (D0S), J8.11 (CKS), J8.17 (GND), J8.S1 (SH), J8.S2 (SH), J8.S3 (SH), J8.S4 (SH), R1.2, R4.2, R5.1, R10.1, R12.2, R14.2, R15.2, R16.2, R21.1, R52.2, SW1.2, SW2.2, U1.25 (VSS), U2.5 (GND), U2.6 (GND), U2.36 (GND), U2.39 (GND), U2.40 (GND), U3.2 (GND), U4.19 (TESTEN), U4.57 (GND), U5.4 (GND), U6.4 (GND), U7.4 (V-), U8.2 (GND), Y1.2 (GND), Y1.4 (GND)
unnamed: C3.1, C5.1, U1.6 (VDDCR)
unnamed: C10.1, FB3.2, J2.1 (VBUS1), J2.5 (VBUS2)
unnamed: C12.1, R17.1, Y1.3 (OUT/IN)
unnamed: C23.1, C24.1, R26.2, U6.5 (VCC)
unnamed: C27.2, R27.2, R29.1
unnamed: C28.2, R28.2, R30.1
unnamed: C29.1, R30.2, U7.5 (+)
unnamed: C30.1, R29.2, U7.3 (+)
unnamed: C35.2, R51.2, R52.1, U8.6 (FB)
unnamed: D1.1 (K), R39.1
unnamed: J1.A5 (CC1), R1.1
unnamed: J1.B5 (CC2), R4.1
unnamed: J3.10, R10.2
unnamed: J3.12, R11.2
unnamed: L1.1, U8.3 (SW)
unnamed: R5.2, U1.24 (RBIAS)
unnamed: R27.1, U6.8 (RCH)
unnamed: R28.1, U6.6 (LCH)

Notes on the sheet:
CLOCK GPOUT1
M O Z A R T
nINTSEL has internal pull-up, which selects REF_CLK In mode
0.6 * (1 + (200/44.2)) = 3.3149
SD CARD
SPI1 CS
MUST USE 2.5V/3.3V FLASH
C1=15pF, C2=15pF, CL=12pF, Cstray=5, (C1*C2)/(C1+C2)+Cstray == CL
UART1 TX
REGOFF has internal pull-down, which enables internal 1.2V regulator
POWER
SECHZIG
SPI1 RX
SPI1 TX
ETHERNET
CLOCK GPIN1
USB POWER/CONFIG DEVICE (RP2040)
CLOCK GPOUT0
SUPERVISOR
AUDIO
USB HOST
SPI1 SCK
UART1 RX

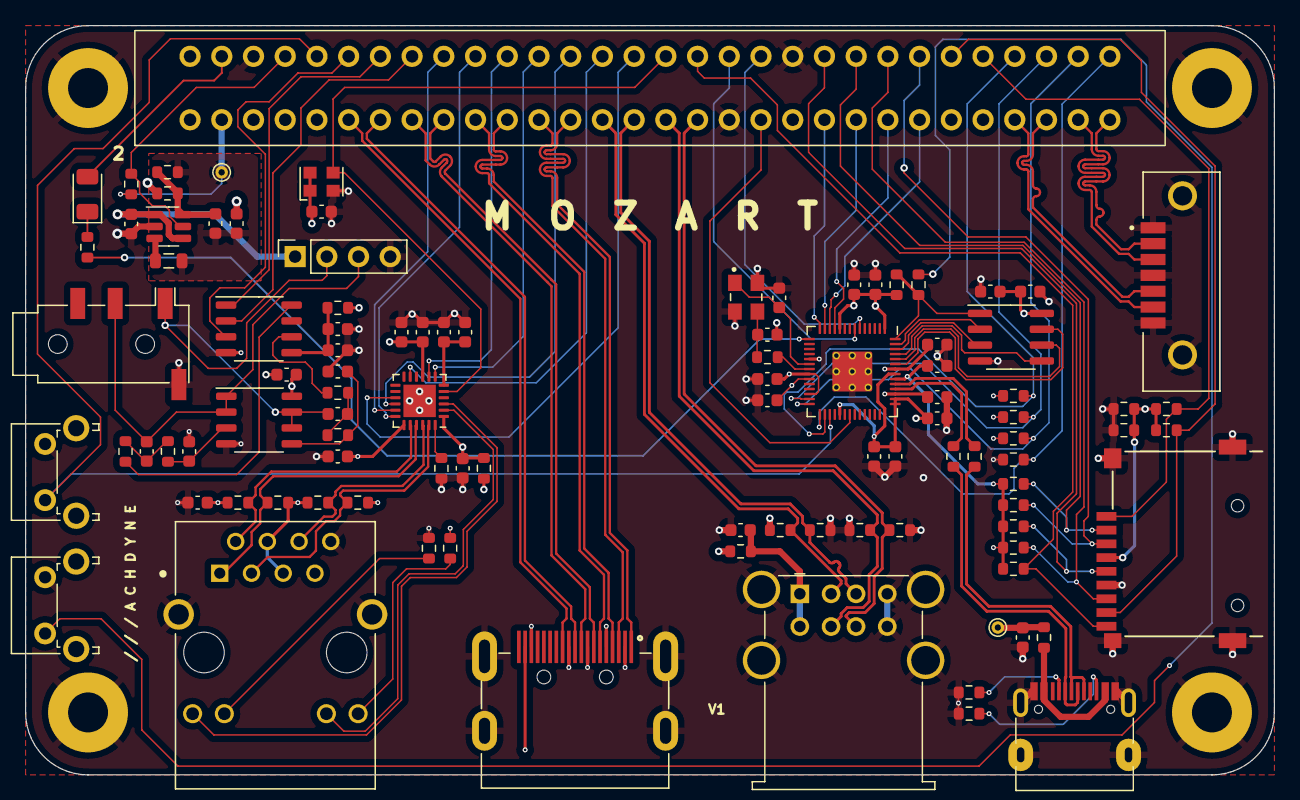
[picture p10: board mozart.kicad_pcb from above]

Board: 4 copper layers, 100.0 x 60.0 mm, 104 parts (0 on the bottom side), 94 nets.

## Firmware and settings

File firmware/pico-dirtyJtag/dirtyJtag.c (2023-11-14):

#include <stdio.h>
#include "pico/stdlib.h"
#include "pico/binary_info.h"
#include "hardware/pio.h"
#include "pico/multicore.h"
#include "pio_jtag.h"
#include "cdc_uart.h"
#include "led.h"
#include "bsp/board.h"
#include "tusb.h"
#include "cmd.h"
#include "get_serial.h"

#include "dirtyJtagConfig.h"

#include "hardware/pll.h"
#include "hardware/clocks.h"
#include "hardware/structs/pll.h"
#include "hardware/structs/clocks.h"

#define MULTICORE

void init_pins()
{
    bi_decl(bi_4pins_with_names(PIN_TCK, "TCK", PIN_TDI, "TDI", PIN_TDO, "TDO", PIN_TMS, "TMS"));
    #if !( BOARD_TYPE == BOARD_QMTECH_RP2040_DAUGHTERBOARD )
    bi_decl(bi_2pins_with_names(PIN_RST, "RST", PIN_TRST, "TRST"));
    #endif
}

pio_jtag_inst_t jtag = {
            .pio = pio0,
            .sm = 0
};

void djtag_init()
{
    init_pins();
    #if !( BOARD_TYPE == BOARD_QMTECH_RP2040_DAUGHTERBOARD )
    init_jtag(&jtag, 1000, PIN_TCK, PIN_TDI, PIN_TDO, PIN_TMS, PIN_RST, PIN_TRST);
    #else
    init_jtag(&jtag, 1000, PIN_TCK, PIN_TDI, PIN_TDO, PIN_TMS, 255, 255);
    #endif

    #if ( BOARD_TYPE == BOARD_MOZART )
    clock_gpio_init(MOZART_CLKOUT, CLOCKS_CLK_GPOUT1_CTRL_AUXSRC_VALUE_CLK_USB, 1);
    #endif
}
typedef uint8_t cmd_buffer[64];
static uint wr_buffer_number = 0;
static uint rd_buffer_number = 0; 
typedef struct buffer_info
{
    volatile uint8_t count;
    volatile uint8_t busy;
    cmd_buffer buffer;
} buffer_info;

#define n_buffers (4)

buffer_info buffer_infos[n_buffers];

static cmd_buffer tx_buf;

void jtag_main_task()
{
#ifdef MULTICORE
    if (multicore_fifo_rvalid())
    {
        //some command processing has been done
        uint rx_num = multicore_fifo_pop_blocking();
        buffer_info* bi = &buffer_infos[rx_num];
        bi->busy = false;

    }
#endif
    if ((buffer_infos[wr_buffer_number].busy == false)) 
    {
        //If tud_task() is called and tud_vendor_read isn't called immediately (i.e before calling tud_task again)
        //after there is data available, there is a risk that data from 2 BULK OUT transaction will be (partially) combined into one
        //The DJTAG protocol does not tolerate this. 
        tud_task();// tinyusb device task
        if (tud_vendor_available())
        {
            led_rx( 1 );
            uint bnum = wr_buffer_number;
            uint count = tud_vendor_read(buffer_infos[wr_buffer_number].buffer, 64);
            if (count != 0)
            {
                buffer_infos[bnum].count = count;
                buffer_infos[bnum].busy = true;
                wr_buffer_number = wr_buffer_number + 1; //switch buffer
                if (wr_buffer_number == n_buffers)
                {
                    wr_buffer_number = 0; 
                }
#ifdef MULTICORE
                multicore_fifo_push_blocking(bnum);
#endif
            }
            led_rx( 0 );
        } else {
#if ( USB_CDC_UART_BRIDGE )           
            cdc_uart_task();
#endif
        }
    }
}

void jtag_task()
{
#ifndef MULTICORE
    jtag_main_task();
#endif
}

#ifdef MULTICORE
void core1_entry() {

    djtag_init();
    while (1)
    {
        uint rx_num = multicore_fifo_pop_blocking();
        buffer_info* bi = &buffer_infos[rx_num];
        assert (bi->busy);
        cmd_handle(&jtag, bi->buffer, bi->count, tx_buf);
        multicore_fifo_push_blocking(rx_num);
    }
 
}
#endif

void fetch_command()
{
#ifndef MULTICORE
    if (buffer_infos[rd_buffer_number].busy)
    {
        cmd_handle(&jtag, buffer_infos[rd_buffer_number].buffer, buffer_infos[rd_buffer_number].count, tx_buf);
        buffer_infos[rd_buffer_number].busy = false;
        rd_buffer_number++; //switch buffer
        if (rd_buffer_number == n_buffers)
        {
            rd_buffer_number = 0; 
        }
    }
#endif
}

//this is to work around the fact that tinyUSB does not handle setup request automatically
//Hence this boiler plate code
bool tud_vendor_control_xfer_cb(uint8_t rhport, uint8_t stage, tusb_control_request_t const * request)
{
    if (stage != CONTROL_STAGE_SETUP) return true;
    return false;
}

int main()
{
    board_init();
    usb_serial_init();
    tusb_init();

    led_init( LED_INVERTED, PIN_LED_TX, PIN_LED_RX, PIN_LED_ERROR );
#if ( USB_CDC_UART_BRIDGE )
    cdc_uart_init( PIN_UART, PIN_UART_RX, PIN_UART_TX );
#endif

#ifdef MULTICORE
    multicore_launch_core1(core1_entry);
#else 
    djtag_init();
#endif
    while (1) {
        jtag_main_task();
        fetch_command();//for unicore implementation
    }
}

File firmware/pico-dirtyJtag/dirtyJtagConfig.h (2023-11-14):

#ifndef DirtyJtagConfig_h
#define DirtyJtagConfig_h

// Set to 0 to disable USB-CDC-UART bridge
#define USB_CDC_UART_BRIDGE  1


#define BOARD_PICO           0
#define BOARD_ADAFRUIT_ITSY  1
#define BOARD_SPOKE_RP2040   2
#define BOARD_QMTECH_RP2040_DAUGHTERBOARD 3
#define BOARD_WERKZEUG       4
#define BOARD_MOZART         5

// Select the board type from the above
#define BOARD_TYPE BOARD_MOZART
//#define BOARD_TYPE BOARD_ADAFRUIT_ITSY
//#define BOARD_TYPE BOARD_SPOKE_RP2040
//#define BOARD_TYPE BOARD_WERKZEUG
//#define BOARD_TYPE BOARD_QMTECH_RP2040_DAUGHTERBOARD

// General mapping
// TDI  SPIO RX
// TDO  SPIO TX
// TCK  SPIO SCK
// TMS  SPIO CS
// RST  GPIO
// TRST GPIO

#if ( BOARD_TYPE == BOARD_PICO )

#define PIN_TDI 16 
#define PIN_TDO 17
#define PIN_TCK 18
#define PIN_TMS 19
#define PIN_RST 20
#define PIN_TRST 21

#define LED_INVERTED   0
#define PIN_LED_TX     25
#define PIN_LED_ERROR  25
#define PIN_LED_RX     25

#if ( USB_CDC_UART_BRIDGE )
#define PIN_UART       uart0
#define PIN_UART_TX    12
#define PIN_UART_RX    13
#endif // USB_CDC_UART_BRIDGE

#elif ( BOARD_TYPE == BOARD_ADAFRUIT_ITSY )

#define PIN_TDI 28 
#define PIN_TDO 27
#define PIN_TCK 26
#define PIN_TMS 29
#define PIN_RST 24
#define PIN_TRST 25

// no regular LEDs on the Itsy - it's a neopixel
#define LED_INVERTED   0
#define PIN_LED_TX     -1
#define PIN_LED_ERROR  -1
#define PIN_LED_RX     -1

#if ( USB_CDC_UART_BRIDGE )
#define PIN_UART       uart0
#define PIN_UART_TX    0
#define PIN_UART_RX    1
#endif // USB_CDC_UART_BRIDGE

#elif ( BOARD_TYPE == BOARD_SPOKE_RP2040 )

#define PIN_TDI 23 
#define PIN_TDO 20
#define PIN_TCK 22
#define PIN_TMS 21
#define PIN_RST 26
#define PIN_TRST 27

#define LED_INVERTED   1
#define PIN_LED_TX     16
#define PIN_LED_ERROR  17
#define PIN_LED_RX     18

#if ( USB_CDC_UART_BRIDGE )
#define PIN_UART       uart0
#define PIN_UART_TX    28
#define PIN_UART_RX    29
#endif // USB_CDC_UART_BRIDGE


#elif ( BOARD_TYPE == BOARD_WERKZEUG )

#define PIN_TDI 1
#define PIN_TDO 2
#define PIN_TCK 0
#define PIN_TMS 3
#define PIN_RST 4
#define PIN_TRST 5

#define LED_INVERTED   1
#define PIN_LED_TX     20
#define PIN_LED_ERROR  21
#define PIN_LED_RX     20

#if ( USB_CDC_UART_BRIDGE )
#define PIN_UART       uart0
#define PIN_UART_TX    28
#define PIN_UART_RX    29
#endif // USB_CDC_UART_BRIDGE

#elif ( BOARD_TYPE == BOARD_MOZART )

#define MOZART_CLKOUT 23

#define PIN_TCK 18
#define PIN_TDI 16
#define PIN_TDO 17
#define PIN_TMS 19
#define PIN_RST 20
#define PIN_TRST 21

#define LED_INVERTED   1
#define PIN_LED_TX     12
#define PIN_LED_ERROR  13
#define PIN_LED_RX     12

#if ( USB_CDC_UART_BRIDGE )
#define PIN_UART       uart1
#define PIN_UART_TX    4
#define PIN_UART_RX    5
#endif // USB_CDC_UART_BRIDGE


#elif ( BOARD_TYPE == BOARD_QMTECH_RP2040_DAUGHTERBOARD )

// in rp2040 daughterboard UART pins are connected to FPGA pins
// depending on the FPGA pin configuration there is a possibility
// of damage so these pins are not going to be setup
#define USB_CDC_UART_BRIDGE  0

#define PIN_TDI  16 
#define PIN_TDO  17
#define PIN_TCK  18
#define PIN_TMS  19
// in rp2040 daughterboard these pins are connected to FPGA pins
// depending on the FPGA pin configuration there is a possibility
// of damage so these pins are not going to be setup
// #define PIN_RST  X
// #define PIN_TRST X

#define LED_INVERTED   0
#define PIN_LED_TX     25
#define PIN_LED_ERROR  25
#define PIN_LED_RX     25

#endif // BOARD_TYPE

#endif // DirtyJtagConfig_h

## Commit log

2023-12-04 add preliminary case design
    [mozart.scad]
2023-12-15 case improvements
    [mozart.scad]
2023-12-15 update case notes
    [mozart.scad]
2023-12-17 update case
    [mozart.scad]
2024-03-10 add box case
    [mozart_box.scad]
2024-05-12 update box case
    [mozart_box.scad]

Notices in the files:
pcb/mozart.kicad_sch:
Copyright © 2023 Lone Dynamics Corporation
